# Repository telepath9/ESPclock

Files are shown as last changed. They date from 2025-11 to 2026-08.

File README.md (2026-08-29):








---



is a smart clock that connects to a NTP server to get the current time. 
It uses a ESP8266 (Wemos D1 mini) or ESP32 (XIAO ESP32 C3)

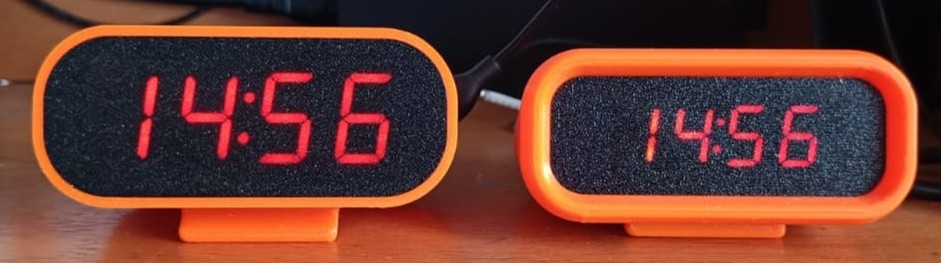
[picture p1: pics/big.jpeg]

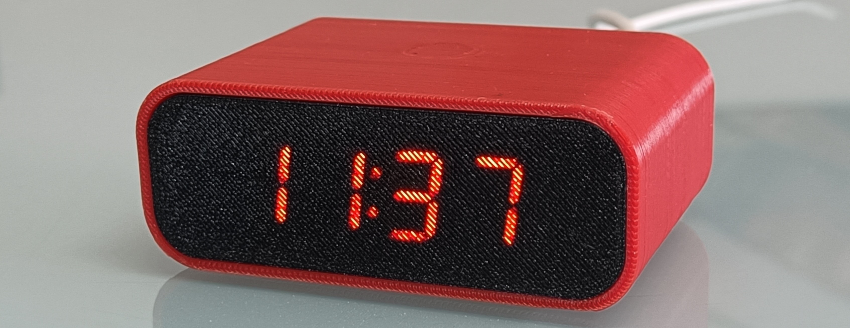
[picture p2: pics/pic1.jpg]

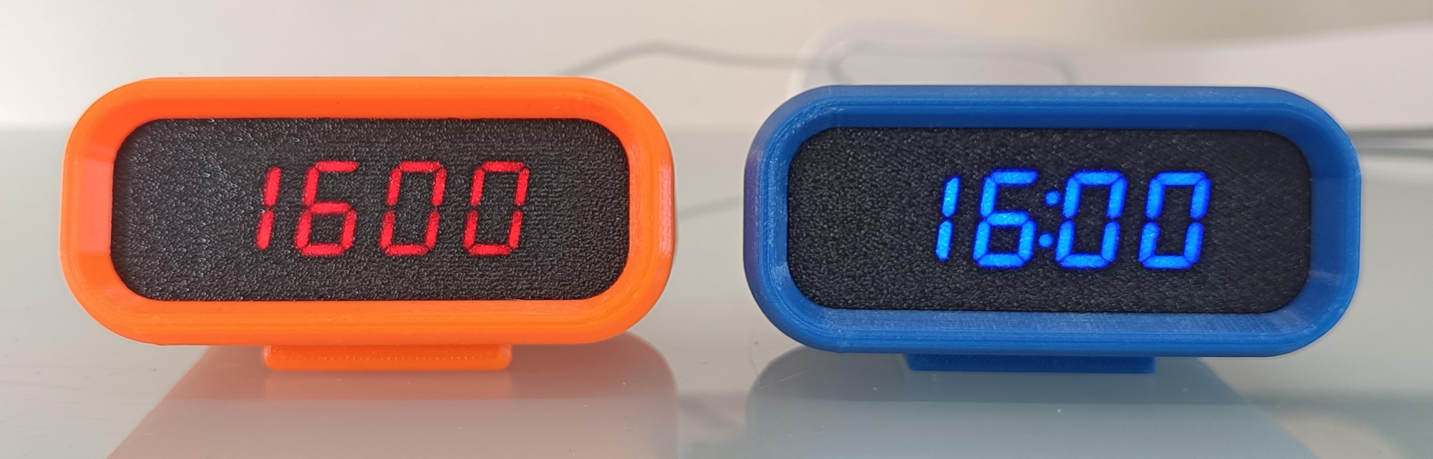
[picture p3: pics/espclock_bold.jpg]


<h2>📜 INSTRUCTIONS </h2>
<details>
<summary><b>(Click to expand)</b></summary>

1. Install VSCode or <b>VSCodium</b> (i prefer VSCodium because it basically is VSCode but <b>without</b> telemetry);

2. Install PIOarduino extension on VSCode/VSCodium;

3. Download the latest .zip file that you can find in the <a href="https://github.com/telepath9/ESPclock/releases"><b>Release</b></a> section, extract it, then open in VSCode/VSCodium the ESPclock project directory;

4. Select the PIOarduino extension in VSCode/VSCodium, then you have to store the html page into the esp8266 flash memory in two steps:
	<b>🔴(Be sure to have closed all Serial Monitor instances, otherwise it will fail to upload the fs image)</b>
	1. Platform -> Build filesystem image
	2. Platform -> Upload filesystem image

5. Now lets upload the C/C++ code. Again from the PIOarduino extension in VSCode/VSCodium, go to:
	1. General -> Build
	2. General -> Upload

6. Now let's connect PC or mobile to the ESPclock access point, with the password: waltwhite64

7. After connecting to the ESPclock's AP, open your browser and paste in the address bar: http://192.168.4.1/ or "espclock.local".

8. From the web UI, first add your home network, then the NTP server that matches your region, plus the GMT/UTC offset hour(s).

9. And we're done! Hope that you liked my project! If you have any suggestions, let me know!
</details>

<h2>📱 WEB UI </h2>
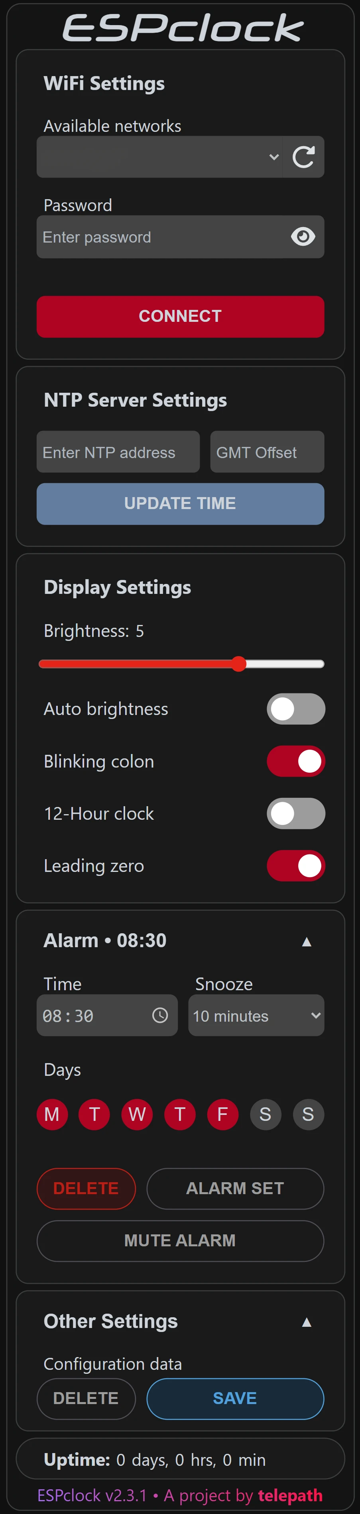
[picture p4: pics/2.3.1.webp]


<h2>🤖 CURRENT FEATURES</h2>

- [x] Asynchronous webserver
- [x] Automatic Wifi Scan</li>
- [x] Wifi and NTP server setup via web UI
- [x] Save/delete configuration (used to restore data after reboot)
- [x] Automatic Brightness mode
- [x] Blinking colon toggle
- [x] ESP32 port
- [x] Replace NTPclient.h with time.h library
- [x] ESPmDNS: web UI can be accessed by simply pasting "espclock.local" in the address bar of the browser.
- [x] 12-Hour clock mode
- [x] Alarm clock mode with buzzer
- [ ] Multiple Alarm (Requested)
- [x] Snooze feature for Alarm clock mode
- [x] Display Uptime in webUI
- [ ] Timezone Support
- [x] Added TTP223 Touch button
- [ ] ESPhome or Homeassistant integration
- [ ] Display Temperature
- [x] TM1652 0.8" display support
- [ ] Web installer

> [!NOTE]
> About ESPmDNS: if more ESPclocks are connected to the same network, in order to access the web UI of second one, user must enter "espclock.local" in the address bar to access to the web UI of the first clock; "espclock.local-2" to access to the seconds clock, and so on...

<h2>🛒 PART LIST</h2>
<details>
<summary><b>TM1637 Display Version</b></summary>
<ul>
<li>XIAO ESP32 C3 or Wemos D1 MINI (mine is V3.0.0 clone)</li>
<li>TM1637 module https://it.aliexpress.com/item/1005001582129952.html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 </li>
<li>Dupont wires</li>
<li>100 Ohm resistor: x1</li>
<li>DG308 7pins terminal block (for XIAO) OR DG308 8pins terminal block (for WEMOS): x2</li>
<li>Female 7pins header(for XIAO) OR Female 8pins header (for WEMOS): x2</li>
<li>7x3cm perfboard: x1</li>
<li>M2.5 screws: x10</li>
<li>M2.5 nuts: x2</li>
<li>Single row female 5pins header (for common GND): x1</li>
<li>Passive Buzzer: x1</li>
<li>(optional) TTP223 Touch button: x1</li>
</ul></details>

<details>
<summary><b>TM1652 Display Version</b></summary>
<ul>
<li>XIAO ESP32 C3 or Wemos D1 MINI (mine is V3.0.0 clone)</li>
<li>TM1652 display https://it.aliexpress.com/item/1005007337668399.html</li>
<li>Dupont wires</li>
<li>100 Ohm resistor: x1</li>
<li>DG308 7pins terminal block (for XIAO) OR DG308 8pins terminal block (for WEMOS): x2</li>
<li>Female 7pins header(for XIAO) OR Female 8pins header (for WEMOS): x2</li>
<li>7x3cm perfboard: x1</li>
<li>M3 screws: x4 (for display's mounting holes)</li>
<li>M2.5 screws: x6</li>
<li>M2.5 nuts: x2</li>
<li>Single row female 5pins header (for common GND): x1</li>
<li>Passive Buzzer: x1</li>
<li>(optional) TTP223 Touch button: x1</li>
</ul>
</details>

<h2>🔌 BOARD WIRING</h2>
<details> 
<summary><b>XIAO ESP32 C3 - TM1652 0.8" Display</b></summary>
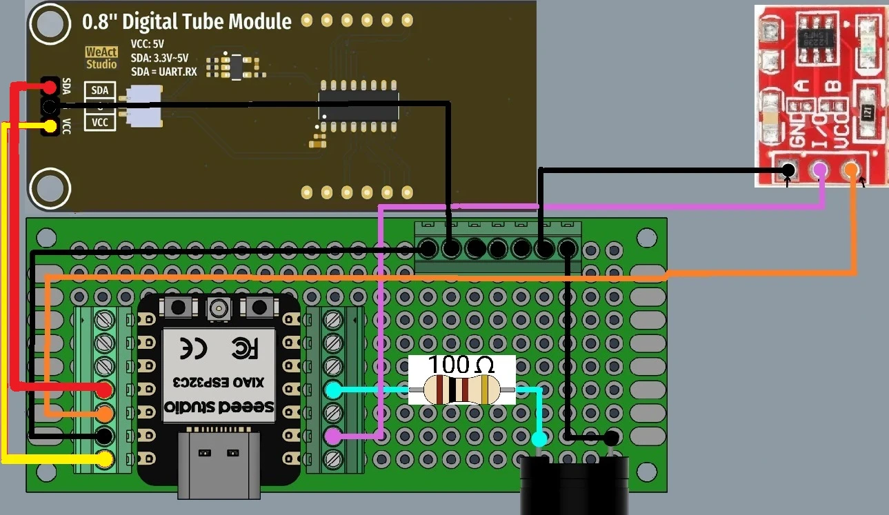
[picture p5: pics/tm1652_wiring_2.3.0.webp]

</details>
<details> 
<summary><b>XIAO ESP32 C3 - TM1637 0.56" Display</b></summary>
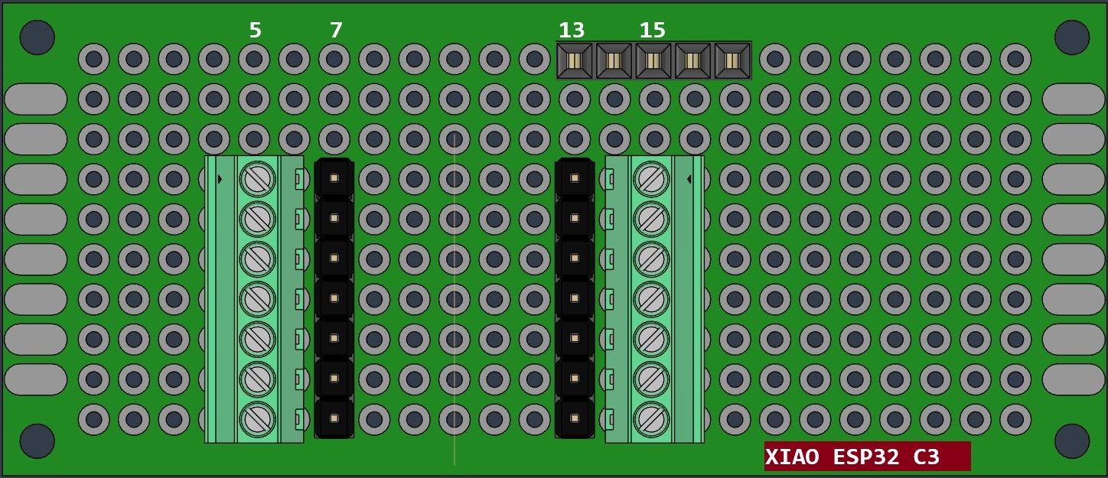
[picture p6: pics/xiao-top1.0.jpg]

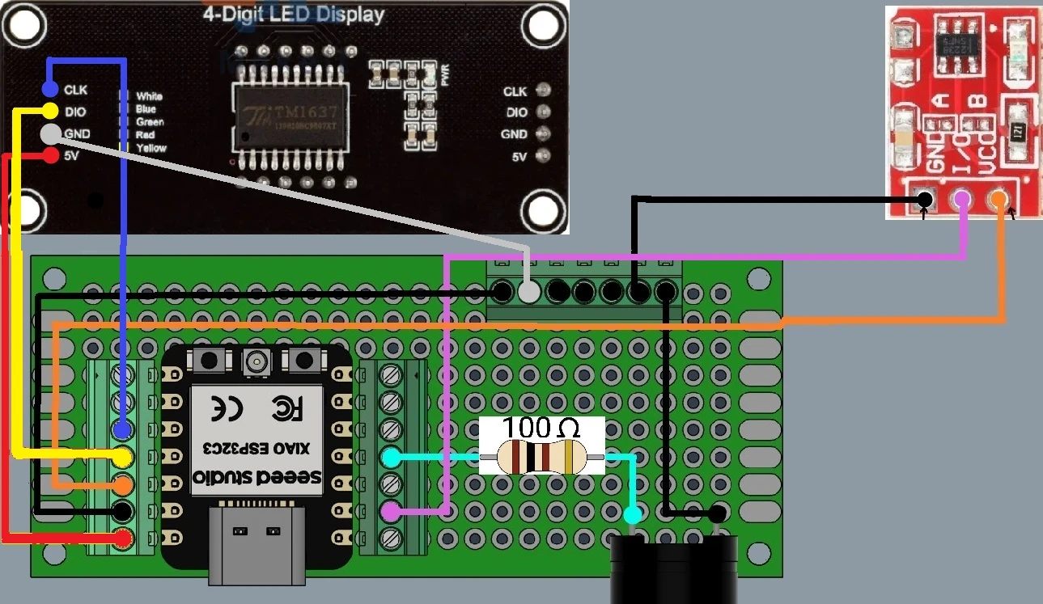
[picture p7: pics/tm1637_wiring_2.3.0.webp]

</details>
<details> 
<summary><b>ESP8266 (Wemos D1 Mini 3.0.0) - TM1637 0.56" Display</b></summary> 
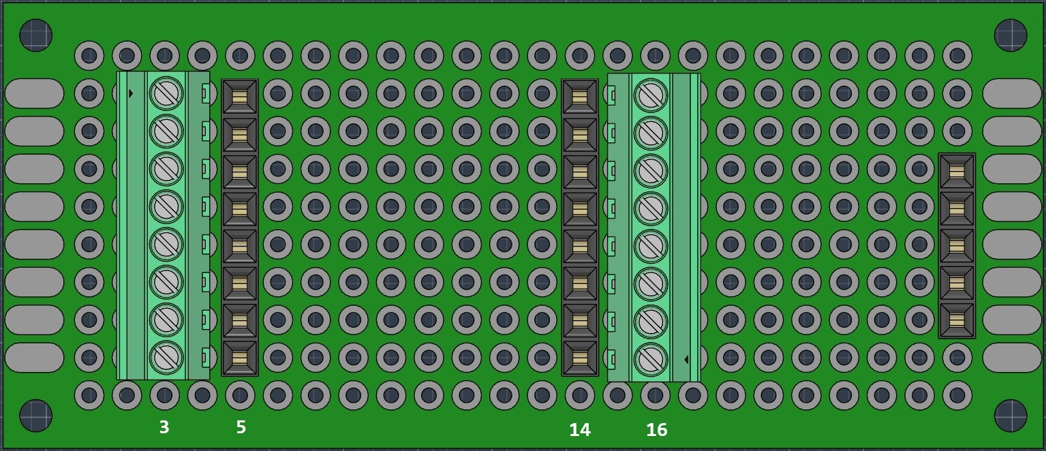
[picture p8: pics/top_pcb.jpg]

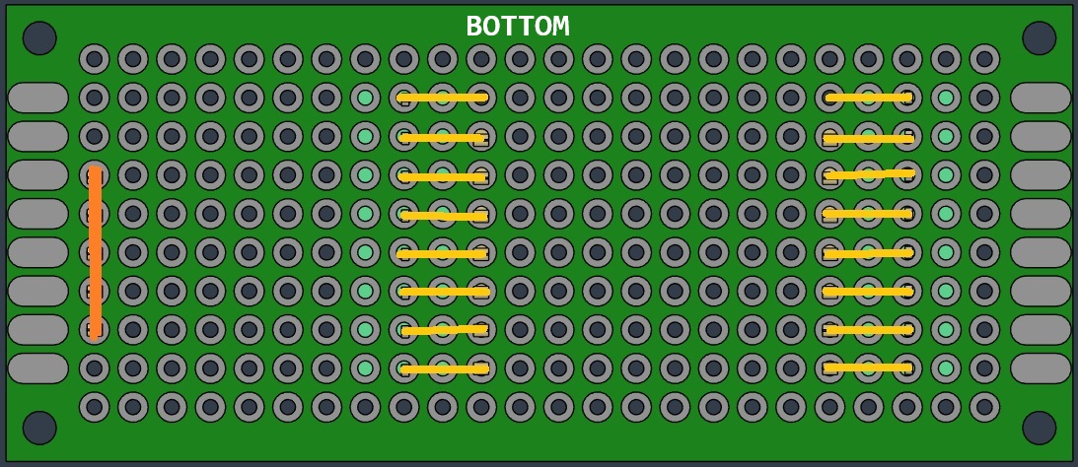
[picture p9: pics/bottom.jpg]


</details>

<h2>🪛 HOW TO ASSEMBLE ESPclock</h2>
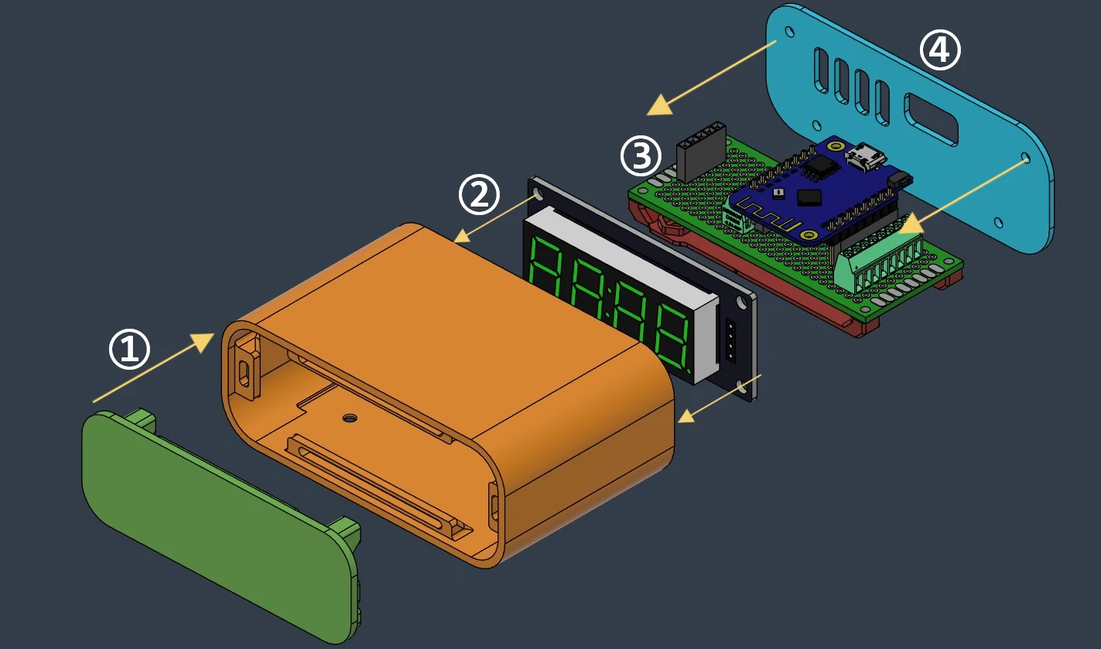
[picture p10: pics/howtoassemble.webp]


<h2>🤝 CODE CONTRIBUTIONS</h2>
This is a personal project which i'm using to learn and to improve my coding skills. So, in order to follow my own plans, I won't accept any pull requests.
If you have any suggestion/advice/feedback, you can open an issue.
Forks are encouranged too, and i'm eager to see new changes that people can add to this project! 

<h2>❤️ SUPPORT</h2>
If you find ESPclock an interesting project, please consider to  <b>star</b> ⭐ the repository!<br>
To not miss the next updates and releases, be sure to click on the  <b>watch</b> 👁️ button!
If you want to financially contribute, contact me.

<h2>👁️ SHOW YOUR BUILD!</h2>
If you've assembled you own build (vanilla or custom), don't forget to post a picture of the final result! You can do it on MakerWorld or in the "Issues" section.

<details> 
<summary><h2>⚠️ TROUBLESHOOTING</h2></summary>
There are (at the moment) two errors that can be displayed from the 7-segment display:
<ul>
<li>Err0 -> when "LittleFS.begin()" fails</li>
<li>Err1 -> when "index.html" doesn't exists in flash memory (user forgot to upload it)</li>
</ul>
</details>

<h2>🙋🏽 SPECIAL THANKS</h2>
To maxint-rd and his <a href="https://github.com/maxint-rd/TM16xx">TM16xx</a> library, the "swiss-army knife" for TM16xx chips.

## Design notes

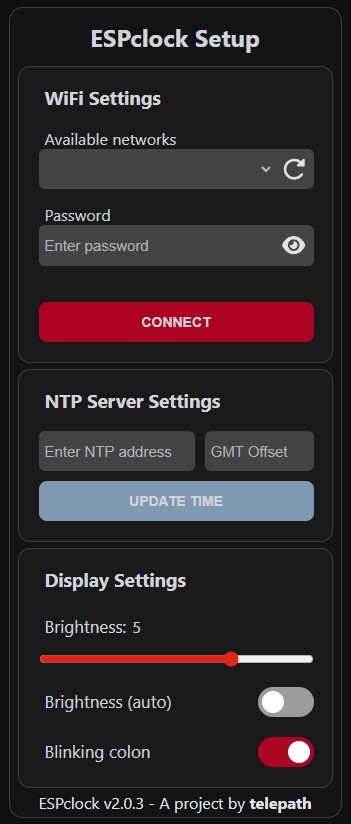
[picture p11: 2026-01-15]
pics/2.0.3.jpg

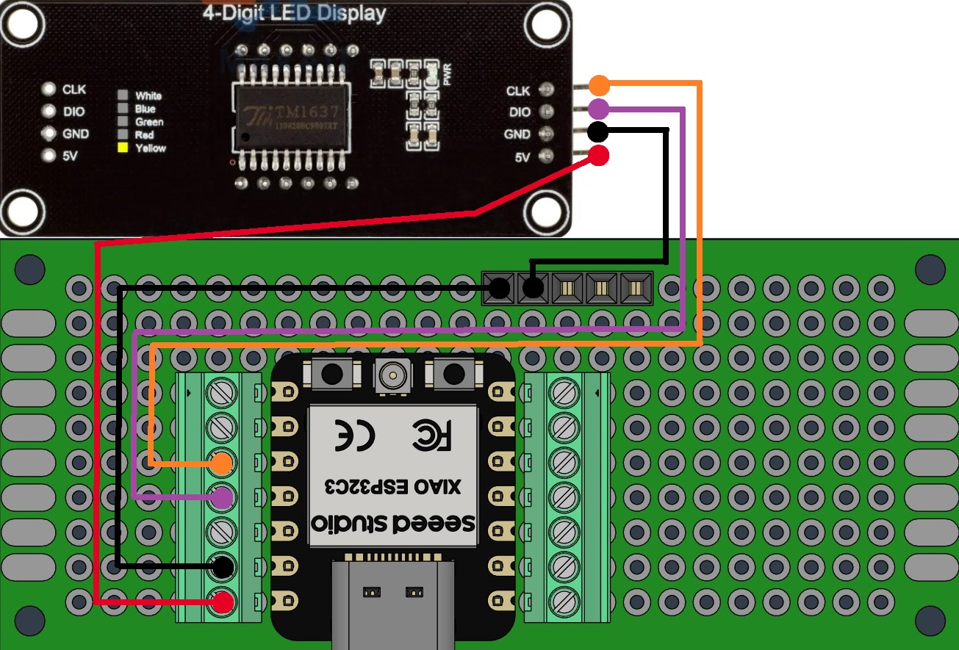
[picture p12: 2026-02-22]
pics/xiao_top3_w.jpg

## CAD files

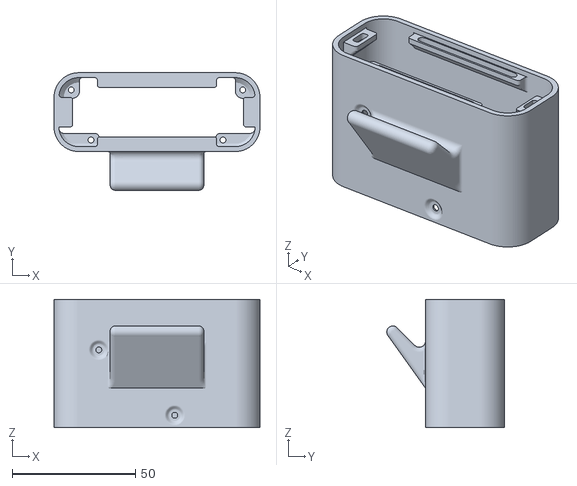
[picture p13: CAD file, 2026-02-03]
3d_models/1. Cases - choose one/CASE_22.3_deg_RISER.stl
83.6 x 47.7 x 52.0

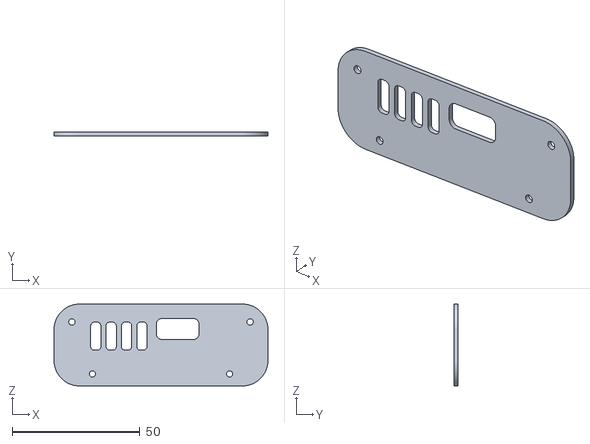
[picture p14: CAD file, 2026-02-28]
3d_models/2. lid+pcb_base - print both/XIAO_back_LID.stl
83.6 x 1.50 x 32.0

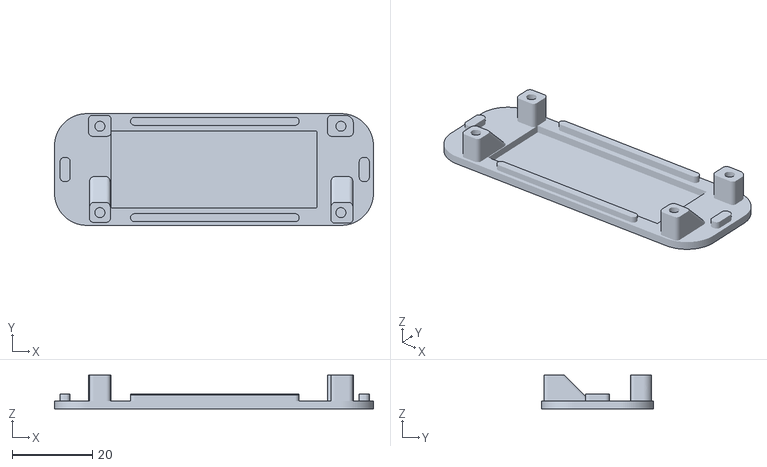
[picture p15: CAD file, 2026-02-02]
3d_models/3. diffusers - print only one/tm_mask +0.4 (toTEST).stl
79.4 x 27.8 x 8.40

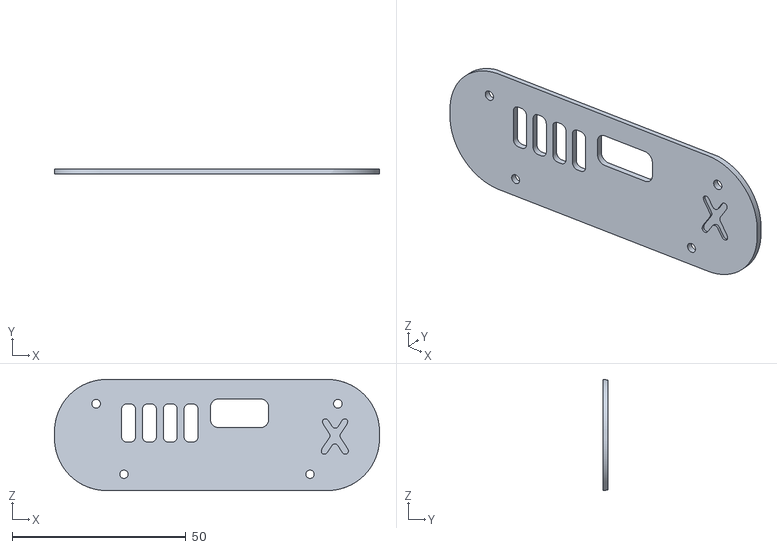
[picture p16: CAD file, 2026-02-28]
3d_models/bold_case/XIAO_BOLD_back_LID.stl
93.6 x 1.50 x 32.0

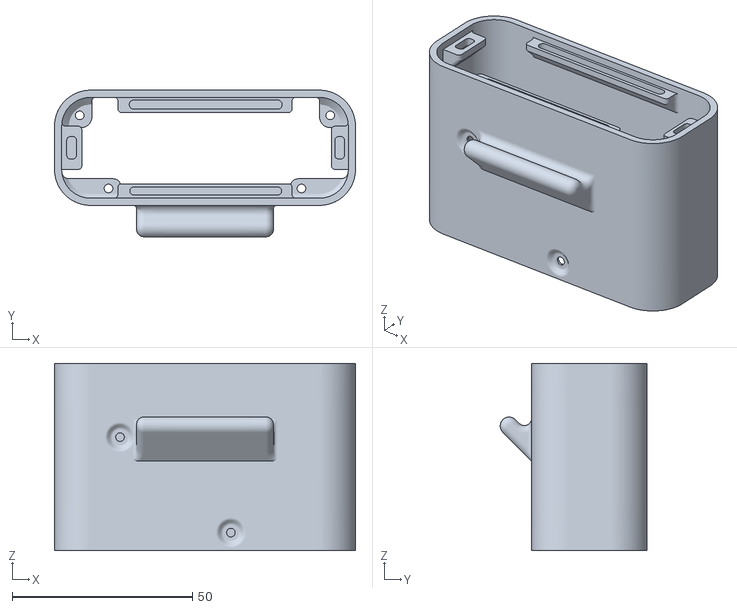
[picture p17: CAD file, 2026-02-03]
3d_models/1. Cases - choose one/CASE_14deg.stl
83.6 x 40.7 x 52.0

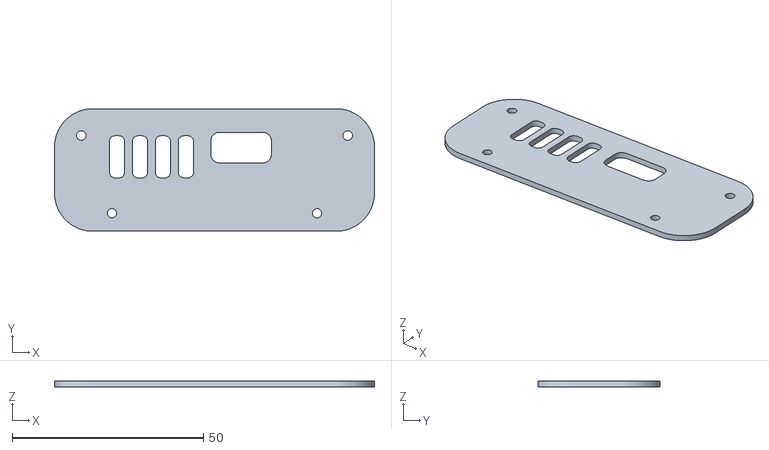
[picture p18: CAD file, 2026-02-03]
3d_models/2. lid+pcb_base - print both/back_LID_ESP8266.stl
83.6 x 32.0 x 1.50

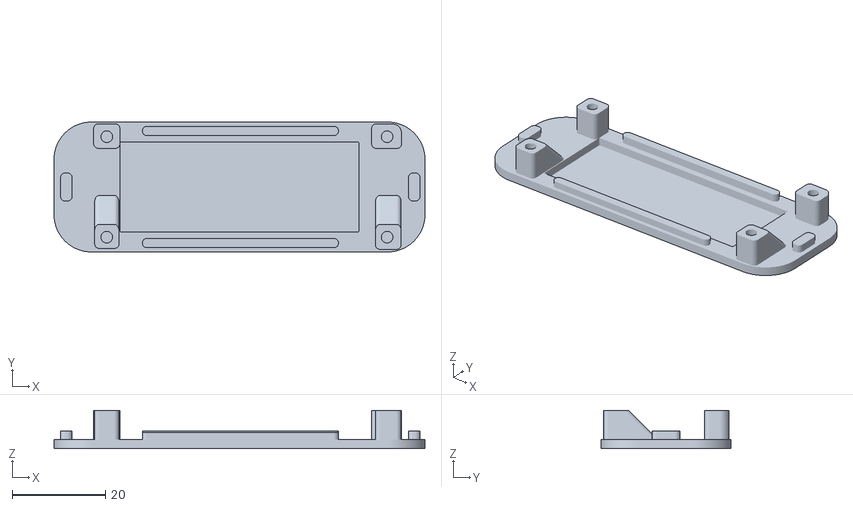
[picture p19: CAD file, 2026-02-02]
3d_models/3. diffusers - print only one/tm_mask +0.2.stl
79.4 x 27.8 x 8.20

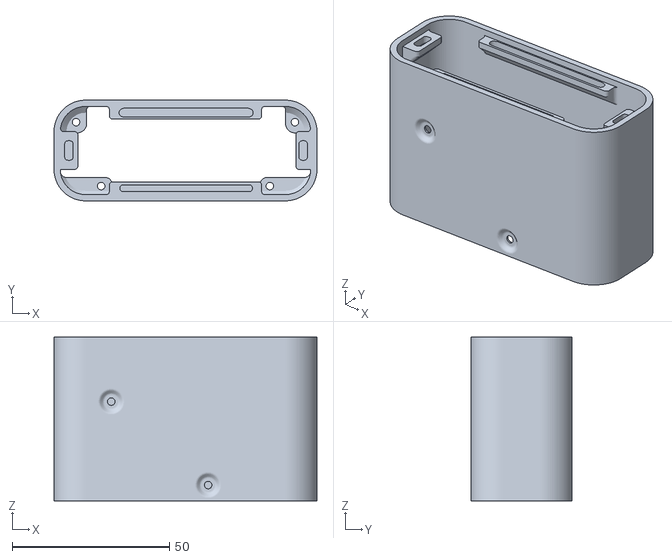
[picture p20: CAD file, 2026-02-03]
3d_models/1. Cases - choose one/standard_case.stl
83.6 x 32.0 x 52.0

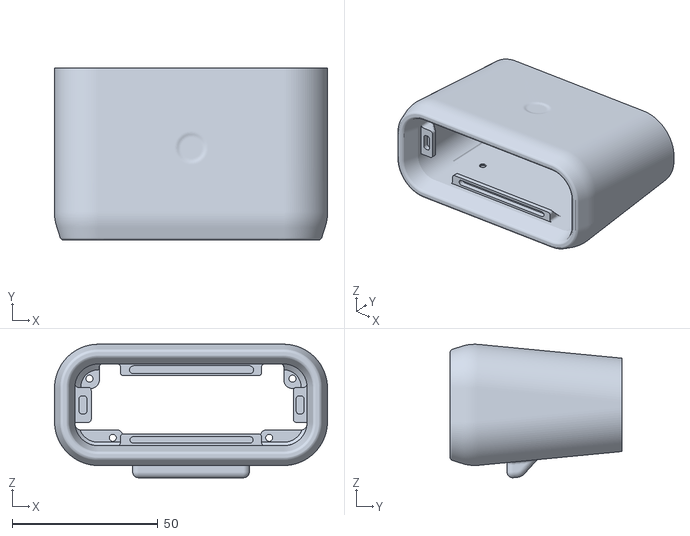
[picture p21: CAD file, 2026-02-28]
3d_models/bold_case/ALT_FILLET_case_BOLD_v1.2_SHELLed.stl
93.6 x 59.0 x 45.8

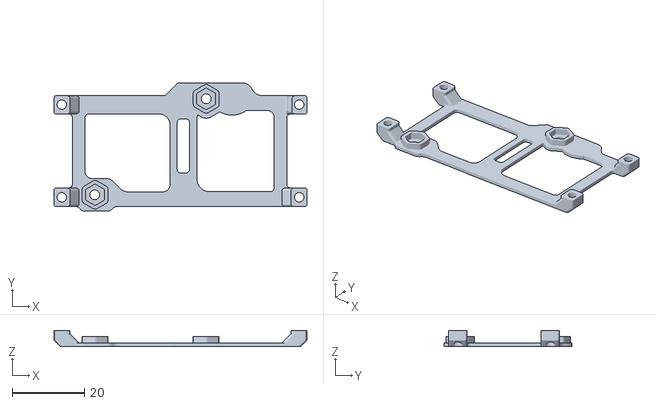
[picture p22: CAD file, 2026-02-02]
3d_models/bold_case/NEW_Base_PCB.stl
69.9 x 35.4 x 4.50

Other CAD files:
3d_models/bold_case/tm_mask_v1.1 +0.2.stl
3d_models/bold_case/lid_BOLD.stl

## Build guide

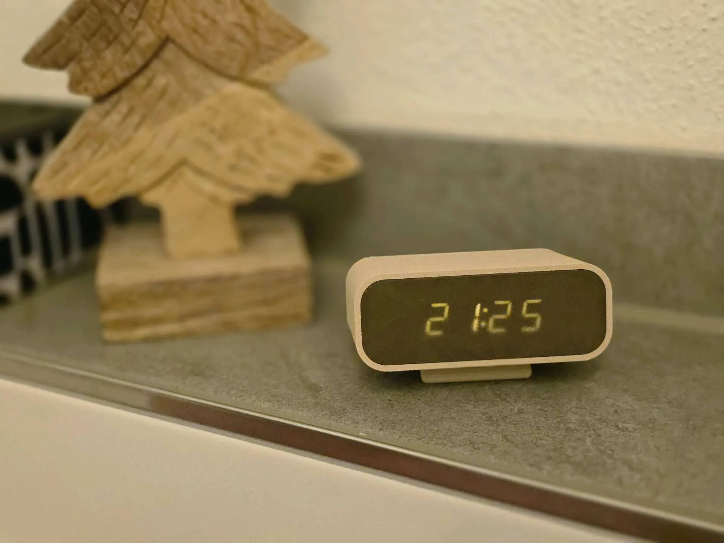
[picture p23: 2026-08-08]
pics/community_builds/1.webp

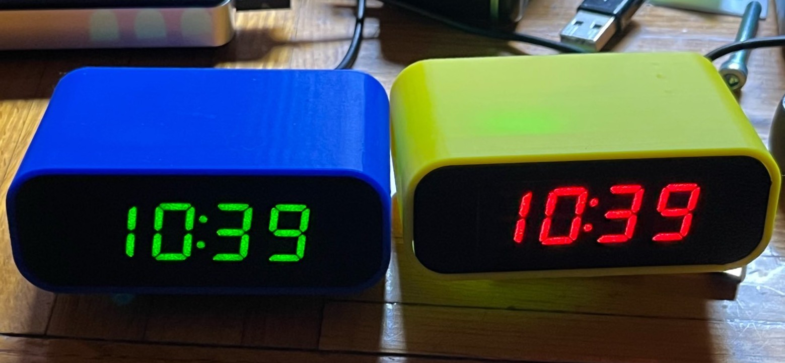
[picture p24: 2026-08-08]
pics/community_builds/2.jpg

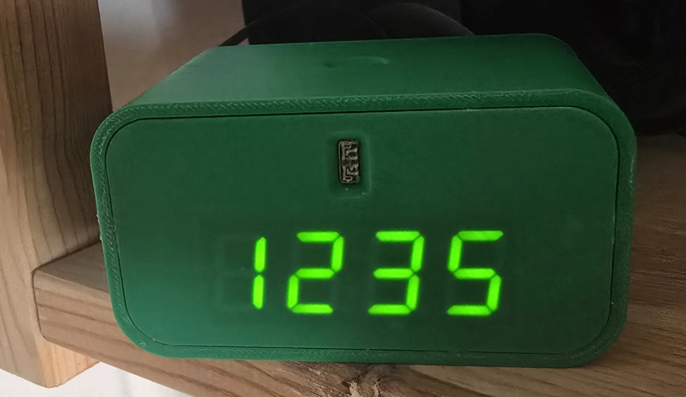
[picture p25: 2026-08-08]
pics/community_builds/4.webp

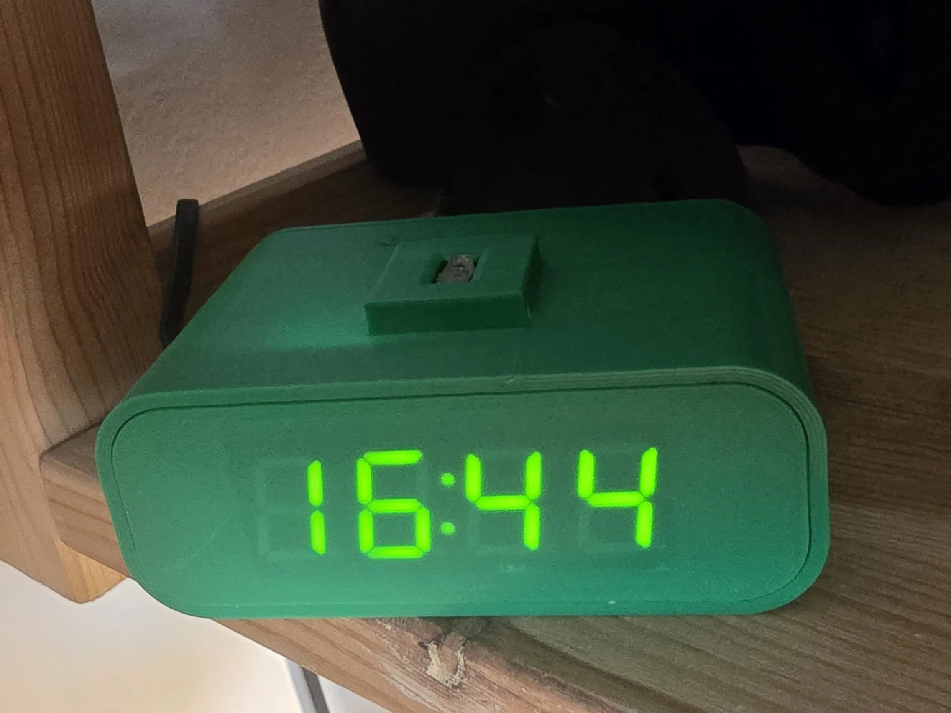
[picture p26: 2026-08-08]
pics/community_builds/3.jpg

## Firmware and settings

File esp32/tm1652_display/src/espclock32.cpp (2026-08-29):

#include <Arduino.h>
#include <WiFi.h>
#include <time.h>
#include <AsyncTCP.h>
#include <ESPAsyncWebServer.h>
#include <WiFiClient.h>
#include <FS.h>            //for file handling
#include <LittleFS.h>      //to access to filesystem
#include <ESPmDNS.h>
#include <ArduinoJson.h>
#include <TM1652.h>
#include <TM16xxDisplay.h>
#include "esp_sntp.h"
#include "tz.h"

//internal temp sensor--> https://docs.espressif.com/projects/esp-idf/en/stable/esp32c3/api-reference/peripherals/temp_sensor.html

//JSON optimizations
#define ARDUINOJSON_SLOT_ID_SIZE 1
#define ARDUINOJSON_STRING_LENGTH_SIZE 1
#define ARDUINOJSON_USE_DOUBLE 0
#define ARDUINOJSON_USE_LONG_LONG 0

//NON-blocking timer function (delay() is EVIL). only accepts milliseconds
unsigned long myTimer(unsigned long everywhen){ //millis-overflow safe!
        static unsigned long t1, diff_time;
        bool ret=0;
        diff_time= millis() - t1;
          
        if(diff_time >= everywhen){
            t1= millis();
            ret=1;
        }
        return ret;
}

//4294967295 ms == 49d 17h 5m

const char* ssid;
const char* password;
bool creds_available=false;
bool connected=false;   //wifi connection state

const char *esp_ssid = "ESPclock32";
const char *esp_password =  "waltwhite64"; //AP pw must be at least 8 chars, otherwise AP won't be customized 

bool newScan = false; //if true, ESP scans for networks again and overrides the previous networks on net_list
uint8_t attempts = 0; //connection attempts --> when it's set to 0 again, it means pw is wrong

AsyncWebServer server(80);

#define BUZZER_PIN 5

//TM1652 DISPLAY SETUP
TM1652 module(10, 4);                 //module(GPIOpin, n_ofdigits); --> creates the low-level driver object for the TM1652 chip
TM16xxDisplay display(&module, 4);   //TM16xxDisplay display(&module, n_ofdigits);

// 7-segment character map (A-F, 0-9, space, dash)
const byte SEG_CHAR_MAP[] = {
  0x77, // A
  0x7C, // b
  0x39, // C
  0x5E, // d
  0x79, // E
  0x71, // F
  0x3F, // 0
  0x06, // 1
  0x5B, // 2
  0x4F, // 3
  0x66, // 4
  0x6D, // 5
  0x7D, // 6
  0x07, // 7
  0x7F, // 8
  0x6F, // 9
  0x00, // space
  0x40  // -
};

//global vars
bool colon=true;  //if blink is ON, this will change every second
bool blink=true;
bool br_auto=false;
bool twelve=false;
bool leadingzero=true;
uint8_t brightness=7;
uint8_t ms_ovfl=0;

String user_tz;
String user_posix;

uint8_t px=4;  
bool alarm_status=false; 
String timehm = "";
bool alarm_stop=0;  //when 0, alarm is active.
uint8_t alarm_hour;
uint8_t alarm_min;
bool forw = true;               //used by displayAnim()

void displayAnim(void){
   if(myTimer(500)){
        if(forw==true){ // 4 -> 0
          display.clear();
          module.setSegments(0x40, px);
          --px;          
          
          if(px==0){
            forw=false;
          }
        }

        else if(forw==false){ //0 -> 4
          display.clear();
          module.setSegments(0x40, px);
          ++px;          
          
          if(px==3){
            forw= true;
          }
        }
  }
  return;
}

//NTP SETUP
struct tm timeinfo;

/*void printLocalTime(){
    struct tm timeinfo;
    if(!getLocalTime(&timeinfo)){
      Serial.println("Failed to obtain time 1");
      return;
    }
    Serial.println(&timeinfo, "%H:%M:%S zone %Z %z ");
    //Serial.println(timeinfo.tm_hour); //access to single time vars
}*/

const char *ntp_addr;
bool start_NtpClient = false;

//ALARM setup
uint8_t hh, mm; //hour n minutes

//all entries are initialized to 0
bool days[7] = {0};   //in this case sun=days[0], mon=days[1], tue=days[2], ...
bool tone_var=0;
uint8_t snooze;
//uint8_t ringtone;

void wifiScan(){
    //---------------------------------------------x
    //start wifiSCAN
    WiFi.disconnect();

    byte n = WiFi.scanNetworks();
    Serial.printf("%d networks found", n);

    //---------------------------------------------x
    //SSIDs found are stored in json
    //arduinoJson7 doesn't use static/dynamicJsonDocument anymore, but it uses only JsonDocument
      
    //If json doesn't exists yet, it creates it
    if(!LittleFS.exists("/network_list.json")){
      JsonDocument net_list;

      net_list["found"] = n;
      JsonArray network = net_list["network"].to<JsonArray>();

      for(byte j = 0; j < n; j++){
        JsonArray network_n_credentials = network[j]["credentials"].to<JsonArray>();
        network_n_credentials.add(WiFi.SSID(j));
        network_n_credentials.add("");
      }
      
      //---------------------------------------------x
      //After creating JSON file (jsondocument) it stores it in FS
      File fx = LittleFS.open("/network_list.json", "w");

      //serializes json and passes it to "fx" var
      serializeJsonPretty(net_list, fx);
      fx.close();
    }


    //---------EXISTING JSON---------------------
    //2. IF JSON ALREADY EXISTS: access to json, reset it, then add new networks to it
    else{
      //Serial.println("Network list already exists! Updating it..."); 
      JsonDocument net_listUp;
     
      //1. fetch and open json from FS, then deserializes it
      File fxup = LittleFS.open("/network_list.json", "w+");
      deserializeJson(net_listUp, fxup);

      net_listUp["found"] = n;
      JsonArray network = net_listUp["network"].to<JsonArray>();
            
      for(byte k = 0; k < n; k++){  //this must be n not n+1 🟠🟠🟠 on esp8266 n+1 creates a corrupted entry for a ssid that doesn't exists

        //dynamically adds, to each entry "k", a new array to the main array "network"
        JsonArray network_n_credentials = network[k]["credentials"].to<JsonArray>();

        //adds SSID name to the entry[k][0]
        network_n_credentials.add(WiFi.SSID(k));

        //adds pw field (initially empty) to entry[k][1] 
        network_n_credentials.add("");
      }
      
      //3. serializing
      serializeJsonPretty(net_listUp, fxup);
      fxup.close();
    }     
}

void checkConfig(void){

    //if(LittleFS.exists("/config.json")){
      Serial.println("Restoring data");
      creds_available=true;

      File fld = LittleFS.open("/config.json", "r");
      JsonDocument load_cf;
      
      DeserializationError error = deserializeJson(load_cf, fld);

      if (error) {
        fld.close();
        Serial.print("deserializeJson() failed: ");
        Serial.println(error.f_str());
        return;
      }

      ssid = load_cf["ssid"];
      password = load_cf["pw"]; 
      
      WiFi.begin(ssid, password);

      //if it restores wifi connection, then it restore the other settings too
      //if it can't restore wifi, then user must go to webUI to make a new config
      while(WiFi.status() != WL_CONNECTED){
          delay(50);
          display.setDisplayToString("trY", 0, 0);

        if(myTimer(3000)){  
          ++attempts;
          module.setDisplayDigit(attempts,3,false);  // show number 7 at position 1 with dot: 7.
        }

        else if(attempts==4){
          attempts=0;
          creds_available = false;
          fld.close(); 
          break;
        }
      }

      if(WiFi.status() == WL_CONNECTED){
        attempts=0;
        connected=true;
        Serial.println("WIFI RESTORED");

        start_NtpClient=true;
        ntp_addr= strdup(load_cf["ntp_ad"]); 
        user_posix= strdup(load_cf["posix_tz"]);
        configTime(0, 0, ntp_addr);        
        setenv("TZ", user_posix.c_str(), 1); 
        tzset();

        user_tz=strdup(load_cf["tz_val"]);
        brightness = (uint8_t)load_cf["br"];
        module.setupDisplay(true, brightness, 6);
        display.clear();
        
        blink=  load_cf["blink"];
        br_auto = load_cf["br_auto"];
        twelve= load_cf["twelve"];
        leadingzero=load_cf["lz"];
        fld.close();
      }
  return;
}

void checkAlarm(){
  if(LittleFS.exists("/alarm.json")){

    File fla = LittleFS.open("/alarm.json", "r");
    JsonDocument load_al;
    DeserializationError error = deserializeJson(load_al, fla);

    if (error) {
      fla.close();
      Serial.print("deserializeJson() failed: ");
      Serial.println(error.f_str());
      return;
    }

    alarm_status= load_al["alarm"];

    //if alarm is set, edit JSON in order to update UI
    if(alarm_status==true){

      timehm= strdup(load_al["timehm"]);
      alarm_hour= load_al["alarm_hour"];
      alarm_min= load_al["alarm_min"];
      snooze= load_al["snooze"];

      String week= strdup(load_al["week"]);
      fla.close();
   
      for(uint8_t n=0; n<7; n++){
        (week.charAt(n)=='1') ? (days[n]= 1) : (days[n] = 0);
      }
    }
  }
}

bool snoozeOn=0;
bool snoozeRing=0;
bool snoozeMsStart=0;
unsigned long snoozeTimer;

void alarm_ring(){  //intermittent RINGING
  if(tone_var){
    tone(BUZZER_PIN, 2000, 900);
    tone_var=0;
  }

  else{
    tone(BUZZER_PIN, 0, 500);
    tone_var=1;
  }
}

//TTP223 DEBOUNCE
unsigned long prevMillis = 0;     // Previous millis
unsigned long elapsedMillis = 0;      // Elapesed millis since touch
unsigned long debounceTime = 800;              // Debounce time for the touch sensor

void alarm_off(){
  elapsedMillis = millis() - prevMillis;

  if(alarm_stop==0 && elapsedMillis > debounceTime){
    alarm_stop=1;
    noTone(BUZZER_PIN); //can happen, sometimes, that the buzzer will ring at a very low volume... if noTone isn't enought to turn it OFF, try using pinMode
    snoozeOn=0;
  }
  prevMillis = millis();
  snoozeMsStart=0;

  //if(ssid && ssid[0]!='\0'){}     //checks if ssid pointer is NULL. then checks if the 1st char is '\0' 
}

//this is called when user requests resources from esp webserver that don't exists
void notFound(AsyncWebServerRequest *request){
    request->send(404, "text/plain", "NOT FOUND");
}

void initMDNS(){
  MDNS.end();

  if (MDNS.begin("espclock")) {
    MDNS.addService("http", "tcp", 80);
  } else {
    Serial.println("mDNS fail");
  }
}
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
void loop() {
  // Serial.println(esp_clk_get_cpu_freq_mhz());

  if(millis() == 4294967295UL){
    ms_ovfl++;  //can lead to a bug because uint8_t max value is 255, but it'll reach this value after 50days*256= 35years of activity
  }

  if(newScan==true){
    wifiScan();
    newScan=false;
  }
    //Serial.println(WiFi.status());                     
  if(start_NtpClient==false && autoConnect() && LittleFS.exists("/config.json")){ 
    checkConfig();
  }
  
  if(start_NtpClient==true){

    /*The getLocalTime() function has an optional timeout parameter in milliseconds (with the default value being 5 seconds).
    This timeout value is used in case there is an NTP server request being made in the background
    (for example when you just called the configTime() function before calling the getLocalTime()
    function).   getLocalTime(&timeinfo, 5000);

    If needed, the getLocalTime() function will
    wait until either a valid system time is received or until the timeout occurs.  The function will return false, if no valid system time was received before the timeout duration occurs.*/
    getLocalTime(&timeinfo);

    if(myTimer(1000)){
        //printLocalTime();
       if(alarm_status==1){

          //1- alarm rings at the right time
          if(days[timeinfo.tm_wday]==true && alarm_stop==0){ //wrap this in a function

            //RING at the exact time entered by user
            if(timeinfo.tm_hour == alarm_hour && timeinfo.tm_min == alarm_min){
              
              alarm_ring();

              if(snooze>0 && snoozeMsStart==0){  
                snoozeMsStart=1;  //activated Once. starts the countdown for the snooze
                //Serial.println("FROM alarm time> snoozeOn=1");
              }
            }
          }

          //2- after alarm time passes, enables snoozetimer and snooze 
          if(timeinfo.tm_min != alarm_min && alarm_stop==0 && snoozeMsStart==1){
            snoozeMsStart=0;  // this makes the code access to this "if" once
            snoozeOn=1; 
            snoozeTimer= millis();
          }

          //RESTORES ALARM FOR NEXT DAY
          else if(timeinfo.tm_min != alarm_min && alarm_stop==1){  //questo ferma il primo allarme ma NON lo snooze (per ora)
            
            if(snooze==0){
              alarm_stop=0;
              noTone(BUZZER_PIN);
            }
            else if(millis() - snoozeTimer >= (snooze+3)*60*1000UL){  //alarm stop is restored after a given time interval
              alarm_stop=0;
              snoozeRing=0;
            }
          }
        }

        if(snoozeRing==1 && alarm_stop==0){
          alarm_ring(); 
        }

        if(br_auto==true){
            switch(timeinfo.tm_hour){
              case 0 || 00: 
              brightness=0;
              module.setupDisplay(true, brightness, 6);
              break;

              case 9:
              brightness=6;
              module.setupDisplay(true, brightness, 6);
              break;

              case 17:
              brightness=3;
              module.setupDisplay(true, brightness, 6);
              break;

              case 20: //maybe i can remove this one and put brightness=2 at 17:00
              brightness=2; 
              module.setupDisplay(true, brightness, 6);
              break;
            }
        }   
        

        if(blink==1){
            if(colon==true){   //colon is ON
              if(!twelve){  //24hr format

                if(timeinfo.tm_hour==00 && leadingzero==false){
                  display.setDisplayToDecNumberAt((timeinfo.tm_hour*100)+timeinfo.tm_min, 0x04, 1, true);
                }

                else{
                  display.setDisplayToDecNumber((timeinfo.tm_hour*100)+timeinfo.tm_min, 0x04, leadingzero);
                }
              }

              //12hr format is on
              else{   
                if(timeinfo.tm_hour > 0 && timeinfo.tm_hour <= 12){ //display from 1:00 to 12:59    //00:00 is never shown --> midnight is 12:00 in this mode!!!
                  display.setDisplayToDecNumber((timeinfo.tm_hour*100)+timeinfo.tm_min, 0x04, leadingzero);
                }

                else{   //🔴🔴🔴🔴🔴🔴🔴🔴🔴🔴🔴🔴🔴🔴🔴🔴🔴🔴🔴🔴🔴
                  display.setDisplayToDecNumber((abs(timeinfo.tm_hour-12)*100)+timeinfo.tm_min, 0x04, leadingzero);
                }
              }
              colon=false;  
          }

          else if(colon==false){//colon is OFF

              if(!twelve){
                if(timeinfo.tm_hour==00 && leadingzero==false){
                  display.setDisplayToDecNumberAt((timeinfo.tm_hour*100)+timeinfo.tm_min, 0, 1, true);
                }
             
                else{
                  display.setDisplayToDecNumber((timeinfo.tm_hour*100)+timeinfo.tm_min, 0, leadingzero);
                }
              }

              //if 12hr mode is active
              else{ 
                if(timeinfo.tm_hour > 0 && timeinfo.tm_hour <= 12){ //display from 1:00 to 12:59    //00:00 is never shown --> midnight is 12:00 in this mode!!!
                  display.setDisplayToDecNumber((timeinfo.tm_hour*100)+timeinfo.tm_min, 0, leadingzero);
                }
                else{
                  display.setDisplayToDecNumber((abs(timeinfo.tm_hour-12)*100)+timeinfo.tm_min, 0, leadingzero);
                }
              }

            colon=true;
          }
        }
        
      else{ //when blink==0
          if(!twelve){

            if(timeinfo.tm_hour==00 && leadingzero==false){
              display.setDisplayToDecNumberAt((timeinfo.tm_hour*100)+timeinfo.tm_min, 0x04, 1, true);
            }

            else{
              display.setDisplayToDecNumber((timeinfo.tm_hour*100)+timeinfo.tm_min, 0x04, leadingzero);
            }
          }

          //if 12hr mode is active
              else{ 
                if(timeinfo.tm_hour > 0 && timeinfo.tm_hour <= 12){ //display from 1:00 to 12:59    //00:00 is never shown --> midnight is 12:00 in this mode!!!
                  display.setDisplayToDecNumber((timeinfo.tm_hour*100)+timeinfo.tm_min, 0x04, leadingzero);
                }
                
                else{
                  display.setDisplayToDecNumber((abs(timeinfo.tm_hour-12)*100)+timeinfo.tm_min, 0x04, leadingzero);
                }
            }
          }
        }
      if(snoozeOn==1 && alarm_stop==0){ 
    
        if(snoozeRing==0 && millis() - snoozeTimer >=  snooze*60*1000UL){   //rings for 1 min... 
          snoozeRing=1; //makes the alarm ring for snooze
        }
        
        //stop interval - OK  
        if(snoozeRing==1 && millis() - snoozeTimer >= (snooze+1)*60*1000UL){  //...then stops
          snoozeOn=0;
          snoozeRing=0;
        }
    }
  }     

  else{
    displayAnim();
  }

  //optimization: instead of using "bool connected", i can only use WL_CONNECTED
  if(connected == false && creds_available == true){
    
    displayAnim();
    WiFi.begin(ssid, password);
    
    while(1){
      displayAnim();
      //cycles here until it's connected to wifi
      if (WiFi.status() != WL_CONNECTED && creds_available==true){
          delay(200);
      }
    
      //once connected, exit form while(1) with break, and then from first if since "connected==true" now
      else if(WiFi.status() == WL_CONNECTED){
        connected = true;
        initMDNS();
        //🔴🔴🔴🔴🔴🔴 After ESP is connected, must delete network_list!!!🔴🔴🔴🔴🔴🔴

        break;
      }

      else if(attempts == 4){
        attempts=0;  //reset "attempts", so it can try a new connection
        creds_available=false;
        Serial.println("LOOP:attempts reset");
        Serial.println(password);
        break; //exit from while(1)
      }
    }
  }
}

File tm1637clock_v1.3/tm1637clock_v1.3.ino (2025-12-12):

#include <NTPClient.h>
#include <ESP8266WiFi.h>
#include <WiFiUdp.h> 
#include "RTClib.h"
#include "TM1637Display.h"

/* Libraries used:
RTC module: https://github.com/adafruit/RTClib
NTP client: https://github.com/arduino-libraries/NTPClient/tree/master
display: https://github.com/avishorp/TM1637/blob/master/TM1637Display.h
*/

//wemos d1 mini (clone)

    // NON-blocking timer function (delay() is EVIL)
    int myTimer(int everywhen){

      static unsigned long t1, diff_time;
      int ret=0;
      diff_time= millis() - t1;
        
      if(diff_time >= everywhen){
        t1= millis();
        ret=1;
      }
      return ret;
    }



//TM1637 DISPLAY SETUP
#define CLK 13
#define DIO 12

    TM1637Display mydisplay(CLK, DIO);
    
//END TM1637 DISPLAY SETUP


  //wifi credentials
  const char *ssid     = "your_ssid";
  const char *password = "your_pw";

  //SETUP NTP
  WiFiUDP ntpUDP;  //NTP server uses UDP communication protocol

// You can specify the time server pool and the offset, (in seconds, es:(3600=1h))
// additionally you can specify the update interval (in milliseconds).
  NTPClient timeClient(ntpUDP, "ntp1.inrim.it", 7200);

  RTC_DS1307 rtc;

void setup() {
    
    Serial.begin(115200);
    mydisplay.setBrightness(7); //display brightness
    pinMode(14, INPUT_PULLUP);


//WIFI connection
    WiFi.begin(ssid, password);
    mydisplay.clear();
    int ct=4;   //counter used for waiting-4-wifi animation

    //cycle that waits for connection
      while (WiFi.status() != WL_CONNECTED ) {
          
           //setSegments(const uint8_t segments[], uint8_t length = 1, uint8_t pos = 0); i'll use for an other animation
  
           if(myTimer(300)){

                  //animation code
                  if(ct<4 && ct>-1){
                  mydisplay.showNumberDecEx(0, 0, false, 1, ct);
                  Serial.println( "Trying to connect. Press button 2 skip 2 RTC" );
                  ct--;          
                  }

                  //clear() needs to be called in order to refresh the display 
                  else if(ct==4){
                    mydisplay.clear();
                    //Serial.println("ct==4" );
                    ct--;
                  }

                  //resetting ct counter
                  else if(ct==-1){
                  ct=4;      
                  //Serial.println("ct== -1");
                  }

            }


              //when button is pressed, skips directly to RTC MODE
              if(digitalRead(14) == LOW){  
                  break;
              }     
      }
    
      if(WiFi.status() == WL_CONNECTED){
          Serial.println("connected!");
          timeClient.begin();
          timeClient.update();
      }


 
//SETUP RTC 

  //this checks if you wired the RTC module the right way
  if (!rtc.begin()) {
    Serial.println("Couldn't find RTC");
    Serial.flush();
    //while (1) delay(10); //comment this if you're not gonna use RTC, uncomment if you want to use RTC
  }

  //checks if RTC hasn't data in it yet
  if (!rtc.isrunning()) {
    Serial.println("RTC is NOT running, let's set the time!");

    // When time needs to be set on a new device, or after a power loss,
    // This line sets the RTC with an explicit date & time, for example to set
    // January 21, 2014 at 3am you would call:
    // rtc.adjust(DateTime(2014, 1, 21, 3, 0, 0));
    rtc.adjust(DateTime(2025, 3, 20, timeClient.getHours(), timeClient.getMinutes(), timeClient.getSeconds()));
    //PS: __DATE__ e __TIME__ are macros that sets the RTC to the date & time this sketch was compiled
  }

}


  byte bgt=7;
  bool blink=true;

void loop() {

  //about BRIGHTNESS CONTROL: i must find a way to replace delay() with a non-blocking timer
  //in order that a single press won't decrease brightness more than 1 point.
  
   if(digitalRead(14) == LOW){ 

    //byte bounce=1;
    
    if(bgt<=7 && bgt>1){
      --bgt;
    }
    else if(bgt==1){
      bgt=7;
    }

    mydisplay.setBrightness(bgt);
     
    Serial.print("BRIGHTNESS: ");
    Serial.println(bgt);         

    delay(400); //need to replace this later...
              }     

  //NTP Mode
  if(WiFi.status() == WL_CONNECTED){
  
  timeClient.update(); //mandatory
 

  //this part of code makes the colon (":") blink on/off every 1sec.
  if(myTimer(1000)){

    if(blink==true){
      //colon is ON
      mydisplay.showNumberDecEx(timeClient.getHours(), 0b01000000, true, 2, 0);
      mydisplay.showNumberDecEx(timeClient.getMinutes(), 0b01000000, true, 2, 2);
      blink=false;
   }

   else if(blink==false){
      //colon is OFF
      mydisplay.showNumberDecEx(timeClient.getHours(), 0, true, 2, 0);
      mydisplay.showNumberDecEx(timeClient.getMinutes(), 0, true, 2, 2);
      blink=true;
      }
      
  }

  }
    
  //RTC Mode (when there's no wifi)
  else{
  DateTime adesso = rtc.now();
 
  mydisplay.showNumberDecEx(adesso.hour(), 0b01000000, true, 2, 0);
  mydisplay.showNumberDecEx(adesso.minute(), 0b01000000, true, 2, 2);
     }
}

   

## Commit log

2026-01-31 Fix error message for network_list.json opening failure
    [espclock8266.cpp]
2026-02-02 3d models
    for people that don't have a makerworld account
    [CASE_14deg.stl, CASE_22.3_deg_RISER.3mf, NEW_Base_PCB.stl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]
2026-02-14 Added Save/delete configuration
    User can now save the current configuration, that esp8266 will use to restore data after reboot/power loss
    [espclock8266.cpp]
2026-02-16 Update README with current and new features
2026-02-21 ESP32 v2.1 firmware released
    The main difference with the esp8266 firmware is that i've completely removed the dependency from the NTPclient.h library. This new firmware just uses the time.h library.
2026-02-21 Update README with ESP32 support details
2026-02-22 Clarify ESP usage and update part list in README
    Updated the README to clarify the usage of ESP8266 or ESP32 and modified the part list accordingly.
2026-02-22 Update TM1637 display pin definitions
2026-02-22 Replaced NTPclient.h with time.h
    [espclock8266.cpp]
2026-02-23 Update image link for ESP32 in README
2026-03-04 Delete esp8266/data directory
    Deleting this because esp32 and esp8266 share the same index.html file
2026-03-31 Update README with part list and wiring details
2026-04-17 added uptime + 12hour clock fix
    [espclock8266.cpp]
2026-04-22 added alarm clock feature
    added alarm clock feature with snooze, plus buzzer and ttp223 touch button to stop it. Also updated web UI
    [espclock32.cpp]
2026-05-19 Wifi reconnects after power outage
    After a power outage happens, wifi routers usually take some minutes (1-3) before putting user online again. With this update, (if there's already a saved configurantion) ESPclock will retry the connection every 2.5 minutes, after the first attempt. This will avoid user to reboot ESPclock everytime a power outage happens.
    [espclock32.cpp]
2026-05-19 Remove 'Alarm OFF' debug print statement
    Remove debug print statement for alarm off event.
2026-05-19 Remove 'Alarm OFF' debug print statement
    Remove debug print statement for alarm off.
2026-06-03 webUI updates
    WebUI: added Mute button + alarm notification + custom logo font
2026-06-15 Revise board wiring and upload instructions in README
    Updated board wiring section and added warning for uploading.
2026-08-08 Fixed leading zero bug at midnight
    [espclock32.cpp]
2026-08-31 Revise README for flash memory upload instructions
    Updated instructions for storing HTML page in flash memory and corrected ESP8266 to ESP32/ESP8266.
2026-09-07 Fix paths in manifest.json for builds
    Updated paths for ESP32-C3 and ESP8266 builds in manifest.
2026-09-07 Revise HTML and styles for ESPclock Web Installer
    Updated the HTML structure and styles for the ESPclock Web Installer, including adding display selection and installation button functionality.
2026-09-07 Fix file paths in TM1652 manifest.json
    Updated file paths for ESP32-C3 builds in manifest.
2026-09-08 Refactor index.html for improved styling and layout
    Updated the HTML structure and styles for the ESPclock Web Installer page, including background gradient and button styles.
2026-09-11 Update README with ESP8266 warning and installation steps
    Added warning for ESP8266 users regarding WPA3 support and suggested upgrade to ESP32. Updated installation steps and formatting for clarity.
2026-10-20 fix 24hr-mode bug at midnight
    - if "leadingzero == off", going from 23:59 to 0:00 would have led to 20:00 because the 1st digit (2) is not cleared.
    Solution: Clearing the display at 0:00 fixes the visualization.
2026-10-25 updated buttons' styling
